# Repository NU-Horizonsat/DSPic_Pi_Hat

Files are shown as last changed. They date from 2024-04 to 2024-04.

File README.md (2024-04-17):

# DSPic_Pi_Hat
A Raspberry Pi hat with a DSPic and USB.

To-do list:

## schematic

- [x] USB
- [x] UART chip
- [x] Verify chip selected 
- [ ] Wire DSPic 
    - [x] Wire dubug port
    - [ ] 1n4148 to MCLR?
    - [x] Add oscillator
    - [ ] Check oscillator
    - [x] Wire ADC pins
    - [ ] Check ADC connections
    - [x] Wire PWM pins
    - [x] ~~Wire i2c~~
        - [x] might not even need that (dont need it)
    - [x] rework connectors
    - [x] Dip switches
    - [x] Status LEDs
- [x] Wire to Pi GPIO
    - [x] Power pins
    - [x] Pi to DSPic
    - [x] Screen connectors
    - [x] Status LEDs
- [x] Add ICSP header
    - [ ] Second header for slave core?
- [x] Add connectors for coil drivers
- [ ] Add chip protection
    - [x] Add linear regulator
    - [x] ~~I2C protection~~
    - [x] PWM protection
    - [x] ADC protection
    - [x] Check to make sure the ESD would work
- [x] Find polyfuse to use
- [x] Find capacitor value for C5
- [x] Find crystal
- [x] Find inductor 
- [x] Finalize resistor and led paring 
- [x] Add connector for other PSU

## PCB
- [ ] Test points
- [ ] Add pcb art
- [x] Assign all footprints
- [x] Proper edge cuts for hat
- [x] Grounded screw holes
- [ ] Check footprints
- [x] Connectors and ESD
- [x] USB c and power
- [x] UART
- [x] DSPic

## Parts to order for hand soldering

| Part  | Number | Link |
| --- | --- | --- |
| Crystal  | 1  | https://www.digikey.com/en/products/detail/kyocera-avx/KC2520Z100-000C15XXK/11610165 |
| Inductor  | 1 | https://www.digikey.com/en/products/detail/delta-electronics-components/0805CS-621EGTS/9763907 |
| Amp Connector | 3 | https://www.digikey.com/en/products/detail/molex/5015680807/1531491 | 
| External Power | 1 | https://www.digikey.com/en/products/detail/molex/5015680207/1531485 | 
| Qwiic | 1 | https://www.digikey.com/short/mfth8vvv |
| Raspi Header | 1 | https://www.digikey.com/en/products/detail/sullins-connector-solutions/SFH11-PBPC-D20-ST-BK/1990093 |
| Programming header | 1 | https://www.digikey.com/en/products/detail/samtec-inc/TD-103-T-A/1105555 | 
| Jumper | 1 | https://www.digikey.com/en/products/detail/mill-max-manufacturing-corp/342-10-102-00-591000/4455936 |
| Fuse | 1 | https://www.digikey.com/en/products/detail/littelfuse-inc/1210L500-12SLWR/12807041 |
| Dip switches | 1 | https://www.digikey.com/en/products/detail/cts-electrocomponents/208-8/20795 |

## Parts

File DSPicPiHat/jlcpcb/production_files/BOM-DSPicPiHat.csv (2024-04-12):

Comment | Designator | Footprint | LCSC
FerriteBead_Small | FB1 | R_1206_3216Metric | C1017
NCP1117-3.3_SOT223 | U12 | SOT-223-3_TabPin2 | C146799
47pf | C16,C17 | C_0805_2012Metric | C14857
10uf | C19,C22 | C_0805_2012Metric | C15850
10nf | C18 | C_0805_2012Metric | C1710
10k | R17,R18,R19,R20,R21,R22,R23,R24,R3 | R_0805_2012Metric | C17414
10 o | R10,R11,R12,R7,R8,R9 | R_0805_2012Metric | C17415
470o | R4,R6 | R_0805_2012Metric | C17710
12pF | C13,C14 | C_0603_1608Metric | C1792
4.7uf | C21 | CP_Elec_4x5.4 | C213488
POWER_Select | SW1 | SW_SPDT_PCM12 | C221841
DF5A6.2CJE_LM | U10,U3,U4,U6,U7,U9 | SOT-553 | C2762689
5.1k | R13,R14 | R_0805_2012Metric | C27834
0.1uf Cer | C10,C11,C12,C15,C20,C5,C6,C9 | C_0805_2012Metric | C28233
USB_C_Receptacle_USB2.0 | J5 | USB_C_Receptacle_HRO_TYPE-C-31-M-12 | C2927038
Led | D1,D10,D11,D2,D3,D6,D7,D8,D9 | LED_0805_2012Metric | C34499
27o | R15,R16 | R_0805_2012Metric | C365278
WS2812B | D12,D13,D4,D5 | LED_WS2812B-2020_PLCC4_2.0x2.0mm | C4154877
FT230XS | U11 | SSOP-16_3.9x4.9mm_P0.635mm | C69082
Conn_01x04_Female | J2 | JST_SH_BM04B-SRSS-TB_1x04-1MP_P1.00mm_Vertical
Fiducial | FID1 | Fiducial_1mm_Mask2mm
0 ohm | R2 | R_0805_2012Metric
0 ohm | R5 | R_0805_2012Metric
0 ohm | R1 | R_0805_2012Metric
Jumper_2_Open | JP1 | PinHeader_1x02_P2.54mm_Vertical
Conn_PIC_ICSP_ICD | J4 | PinHeader_2x03_P2.54mm_Vertical
SW_DIP_x08 | SW2 | SW_DIP_SPSTx08_Slide_9.78x22.5mm_W7.62mm_P2.54mm
MountingHole_Pad | H4 | MountingHole_2.7mm_M2.5_DIN965_Pad
TestPoint | TP1 | TestPoint_Pad_D1.0mm
0 ohm | R25 | R_0805_2012Metric
0 ohm | R26 | R_0805_2012Metric
TestPoint | TP2 | TestPoint_Pad_D1.0mm
100MHz | Y1 | Crystal_SMD_2520-4Pin_2.5x2.0mm
Fiducial | FID3 | Fiducial_1mm_Mask2mm
MountingHole_Pad | H1 | MountingHole_2.7mm_M2.5_DIN965_Pad
DSPIC33CH512MP508T-I_PT | U1 | TQFP-80_12x12mm_P0.5mm
Conn_01x08 | Connector_X1 | Molex_Pico-Clasp_202396-0807_1x08-1MP_P1.00mm_Horizontal
6.33 mH | L1 | L_0805_2012Metric
Fiducial | FID2 | Fiducial_1mm_Mask2mm
Conn_01x08 | Connector_Y1 | Molex_Pico-Clasp_202396-0807_1x08-1MP_P1.00mm_Horizontal
Conn_01x08 | Connector_Z1 | Molex_Pico-Clasp_202396-0807_1x08-1MP_P1.00mm_Horizontal
MountingHole_Pad | H2 | MountingHole_2.7mm_M2.5_DIN965_Pad
PowerInput | J6 | Molex_Pico-Clasp_202396-0207_1x02-1MP_P1.00mm_Horizontal
5 a | F1 | Fuse_1210_3225Metric
Conn_01x09_Female | J1 | PinHeader_1x09_P2.54mm_Vertical
MountingHole_Pad | H3 | MountingHole_2.7mm_M2.5_DIN965_Pad
RasPiHeaders | J8 | PinSocket_2x20_P2.54mm_Vertical

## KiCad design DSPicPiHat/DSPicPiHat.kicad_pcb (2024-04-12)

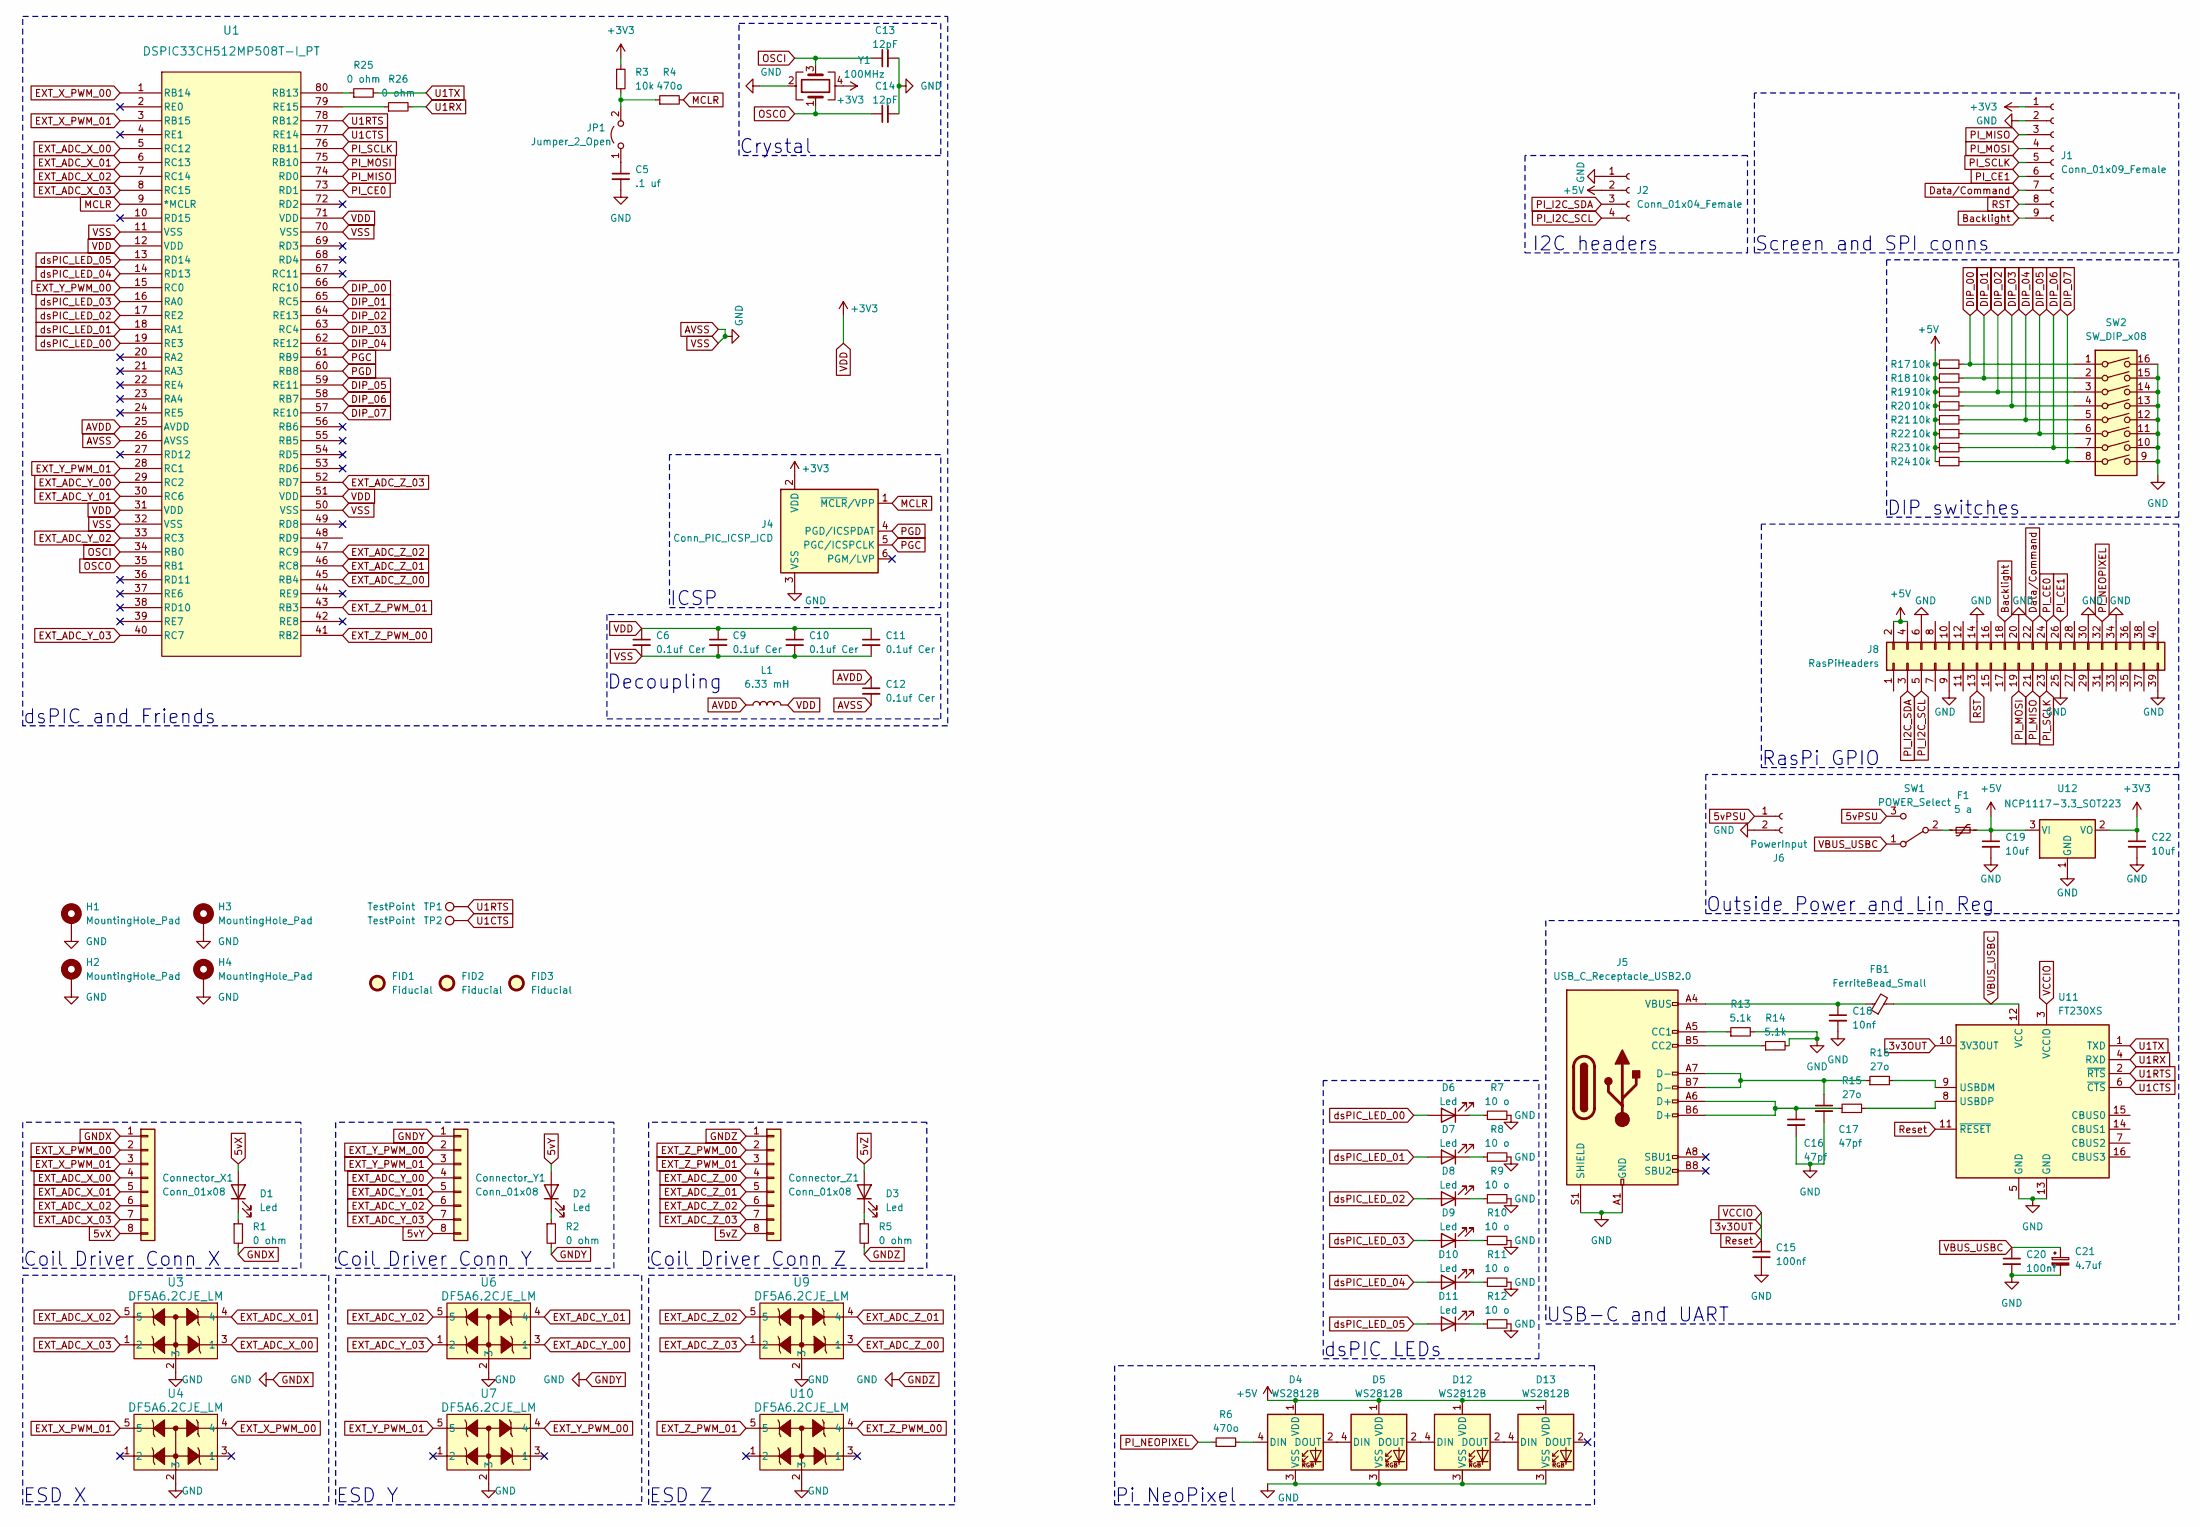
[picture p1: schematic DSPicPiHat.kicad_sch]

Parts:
C5: .1 uf; C_0805_2012Metric
C6, C9, C10, C11, C12: 0.1uf Cer; C_0805_2012Metric
C13, C14: 12pF; C_0603_1608Metric
C15, C20: 100nf; C_0805_2012Metric
C16, C17: 47pf; C_0805_2012Metric
C18: 10nf; C_0805_2012Metric
C19, C22: 10uf; C_0805_2012Metric
C21: 4.7uf; CP_Elec_4x5.4
Connector_X1: Conn_01x08; Molex_Pico-Clasp_202396-0807_1x08-1MP_P1.00mm_Horizontal
Connector_Y1: Conn_01x08; Molex_Pico-Clasp_202396-0807_1x08-1MP_P1.00mm_Horizontal
Connector_Z1: Conn_01x08; Molex_Pico-Clasp_202396-0807_1x08-1MP_P1.00mm_Horizontal
D1, D2, D3, D6, D7, D8, D9, D10, D11: Led; LED_0805_2012Metric
D4, D5, D12, D13: WS2812B; LED_WS2812B-2020_PLCC4_2.0x2.0mm
F1: 5 a; Fuse_1210_3225Metric
FB1: FerriteBead_Small; R_1206_3216Metric
FID1, FID2, FID3: Fiducial; Fiducial_1mm_Mask2mm
H1, H2, H3, H4: MountingHole_Pad; MountingHole_2.7mm_M2.5_DIN965_Pad
J1: Conn_01x09_Female; PinHeader_1x09_P2.54mm_Vertical
J2: Conn_01x04_Female; JST_SH_BM04B-SRSS-TB_1x04-1MP_P1.00mm_Vertical
J4: Conn_PIC_ICSP_ICD; PinHeader_2x03_P2.54mm_Vertical
J5: USB_C_Receptacle_USB2.0; USB_C_Receptacle_HRO_TYPE-C-31-M-12
J6: PowerInput; Molex_Pico-Clasp_202396-0207_1x02-1MP_P1.00mm_Horizontal
J8: RasPiHeaders; PinSocket_2x20_P2.54mm_Vertical
JP1: Jumper_2_Open; PinHeader_1x02_P2.54mm_Vertical
L1: 6.33 mH; L_0805_2012Metric
R1, R2, R5, R25, R26: 0 ohm; R_0805_2012Metric
R3, R17, R18, R19, R20, R21, R22, R23, R24: 10k; R_0805_2012Metric
R4, R6: 470o; R_0805_2012Metric
R7, R8, R9, R10, R11, R12: 10 o; R_0805_2012Metric
R13, R14: 5.1k; R_0805_2012Metric
R15, R16: 27o; R_0805_2012Metric
SW1: POWER_Select; SW_SPDT_PCM12
SW2: SW_DIP_x08; SW_DIP_SPSTx08_Slide_9.78x22.5mm_W7.62mm_P2.54mm
TP1, TP2: TestPoint; TestPoint_Pad_D1.0mm
U1: DSPIC33CH512MP508T-I_PT; TQFP-80_12x12mm_P0.5mm
U3, U4, U6, U7, U9, U10: DF5A6.2CJE_LM; SOT-553
U11: FT230XS; SSOP-16_3.9x4.9mm_P0.635mm
U12: NCP1117-3.3_SOT223; SOT-223-3_TabPin2
Y1: 100MHz; Crystal_SMD_2520-4Pin_2.5x2.0mm

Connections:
3v3OUT: C15.1, U11.3 (VCCIO), U11.10 (3V3OUT), U11.11 (~RESET)
5vPSU: J6.1, SW1.3 (C)
5vX: Connector_X1.8, D1.2 (A)
5vY: Connector_Y1.8, D2.2 (A)
5vZ: Connector_Z1.8, D3.2 (A)
+5V: C19.1, D4.1 (VDD), D5.1 (VDD), D12.1 (VDD), D13.1 (VDD), F1.2, J2.2, J8.2, J8.4, R17.1, R18.1, R19.1, R20.1, R21.1, R22.1, R23.1, R24.1, U12.3 (VI)
AVDD: C12.1, L1.1, U1.25 (AVDD)
AVSS: C5.2, C6.2, C9.2, C10.2, C11.2, C12.2, C13.2, C14.2, C15.2, C16.2, C17.2, C18.2, C19.2, C20.2, C21.2, C22.2, Connector_X1.1, Connector_Y1.1, Connector_Z1.1, D4.3 (VSS), D5.3 (VSS), D12.3 (VSS), D13.3 (VSS), H1.1, H2.1, H3.1, H4.1, J1.2, J2.1, J4.3 (VSS), J5.A1 (GND), J5.A12 (GND), J5.B1 (GND), J5.B12 (GND), J5.S1 (SHIELD), J6.2, J8.6, J8.9, J8.14, J8.20, J8.25, J8.30, J8.34, J8.39, R1.2, R2.2, R5.2, R7.2, R8.2, R9.2, R10.2, R11.2, R12.2, R13.2, R14.2, SW2.9, SW2.10, SW2.11, SW2.12, SW2.13, SW2.14, SW2.15, SW2.16, U1.11 (VSS), U1.26 (AVSS), U1.32 (VSS), U1.50 (VSS), U1.70 (VSS), U3.2 (3), U4.2 (3), U6.2 (3), U7.2 (3), U9.2 (3), U10.2 (3), U11.5 (GND), U11.13 (GND), U12.1 (GND), Y1.2
Backlight: J1.9, J8.18
DIP_00: R17.2, SW2.1, U1.66 (RC10)
DIP_01: R18.2, SW2.2, U1.65 (RC5)
DIP_02: R19.2, SW2.3, U1.64 (RE13)
DIP_03: R20.2, SW2.4, U1.63 (RC4)
DIP_04: R21.2, SW2.5, U1.62 (RE12)
DIP_05: R22.2, SW2.6, U1.59 (RE11)
DIP_06: R23.2, SW2.7, U1.58 (RB7)
DIP_07: R24.2, SW2.8, U1.57 (RE10)
Data/Command: J1.7, J8.22
EXT_ADC_X_00: Connector_X1.4, U1.5 (RC12), U3.3 (1)
EXT_ADC_X_01: Connector_X1.5, U1.6 (RC13), U3.4
EXT_ADC_X_02: Connector_X1.6, U1.7 (RC14), U3.5
EXT_ADC_X_03: Connector_X1.7, U1.8 (RC15), U3.1 (2)
EXT_ADC_Y_00: Connector_Y1.4, U1.29 (RC2), U6.3 (1)
EXT_ADC_Y_01: Connector_Y1.5, U1.30 (RC6), U6.4
EXT_ADC_Y_02: Connector_Y1.6, U1.33 (RC3), U6.5
EXT_ADC_Y_03: Connector_Y1.7, U1.40 (RC7), U6.1 (2)
EXT_ADC_Z_00: Connector_Z1.4, U1.45 (RB4), U9.3 (1)
EXT_ADC_Z_01: Connector_Z1.5, U1.46 (RC8), U9.4
EXT_ADC_Z_02: Connector_Z1.6, U1.47 (RC9), U9.5
EXT_ADC_Z_03: Connector_Z1.7, U1.52 (RD7), U9.1 (2)
EXT_X_PWM_00: Connector_X1.2, U1.1 (RB14), U4.4
EXT_X_PWM_01: Connector_X1.3, U1.3 (RB15), U4.5
EXT_Y_PWM_00: Connector_Y1.2, U1.15 (RC0), U7.4
EXT_Y_PWM_01: Connector_Y1.3, U1.28 (RC1), U7.5
EXT_Z_PWM_00: Connector_Z1.2, U1.41 (RB2), U10.4
EXT_Z_PWM_01: Connector_Z1.3, U1.43 (RB3), U10.5
MCLR: J4.1 (~MCLR/VPP), R4.2, U1.9 (*MCLR)
unnamed: C16.1, J5.A6 (D+), J5.B6 (D+), R15.1
unnamed: C17.1, J5.A7 (D-), J5.B7 (D-), R16.1
unnamed: C18.1, FB1.1, J5.A4 (VBUS), J5.A9 (VBUS), J5.B4 (VBUS), J5.B9 (VBUS)
unnamed: D1.1 (K), R1.1
unnamed: D2.1 (K), R2.1
unnamed: D3.1 (K), R5.1
unnamed: D4.4 (DIN), R6.2
unnamed: D4.2 (DOUT), D5.4 (DIN)
unnamed: D6.1 (K), R7.1
unnamed: D7.1 (K), R8.1
unnamed: D8.1 (K), R9.1
unnamed: D9.1 (K), R10.1
unnamed: D10.1 (K), R11.1
unnamed: D11.1 (K), R12.1
unnamed: D5.2 (DOUT), D12.4 (DIN)
unnamed: D12.2 (DOUT), D13.4 (DIN)
unnamed: J5.A5 (CC1), R13.1
unnamed: J5.B5 (CC2), R14.1
unnamed: C5.1, JP1.1 (A)
unnamed: JP1.2 (B), R3.2, R4.1
unnamed: F1.1, SW1.2 (B)
unnamed: R25.1, U1.80 (RB13)
unnamed: R26.1, U1.79 (RE15)
unnamed: R16.2, U11.9 (USBDM)
unnamed: R15.2, U11.8 (USBDP)
OSCI: C13.1, U1.34 (RB0), Y1.3
OSCO: C14.1, U1.35 (RB1), Y1.1
PGC: J4.5 (PGC/ICSPCLK), U1.61 (RB9)
PGD: J4.4 (PGD/ICSPDAT), U1.60 (RB8)
PI_CE0: J8.24, U1.73 (RD1)
PI_CE1: J1.6, J8.26
PI_I2C_SCL: J2.4, J8.5
PI_I2C_SDA: J2.3, J8.3
PI_MISO: J1.3, J8.21, U1.74 (RD0)
PI_MOSI: J1.4, J8.19, U1.75 (RB10)
PI_NEOPIXEL: J8.32, R6.1
PI_SCLK: J1.5, J8.23, U1.76 (RB11)
RST: J1.8, J8.13
U1CTS: TP2.1, U1.77 (RE14), U11.6 (~CTS)
U1RTS: TP1.1, U1.78 (RB12), U11.2 (~RTS)
U1RX: R26.2, U11.4 (RXD)
U1TX: R25.2, U11.1 (TXD)
VBUS_USBC: C20.1, C21.1, FB1.2, SW1.1 (A), U11.12 (VCC)
VDD: C6.1, C9.1, C10.1, C11.1, C22.1, J1.1, J4.2 (VDD), L1.2, R3.1, U1.12 (VDD), U1.31 (VDD), U1.51 (VDD), U1.71 (VDD), U12.2 (VO), Y1.4
dsPIC_LED_00: D6.2 (A), U1.19 (RE3)
dsPIC_LED_01: D7.2 (A), U1.18 (RA1)
dsPIC_LED_02: D8.2 (A), U1.17 (RE2)
dsPIC_LED_03: D9.2 (A), U1.16 (RA0)
dsPIC_LED_04: D10.2 (A), U1.14 (RD13)
dsPIC_LED_05: D11.2 (A), U1.13 (RD14)

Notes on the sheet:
Decoupling
USB-C and UART
Pi NeoPixel
ICSP
dsPIC LEDs
RasPi GPIO
Screen and SPI conns
Outside Power and Lin Reg
I2C headers
ESD Z
ESD Y
dsPIC and Friends
Coil Driver Conn Y
DIP switches
Crystal
Coil Driver Conn Z
Coil Driver Conn X
ESD X

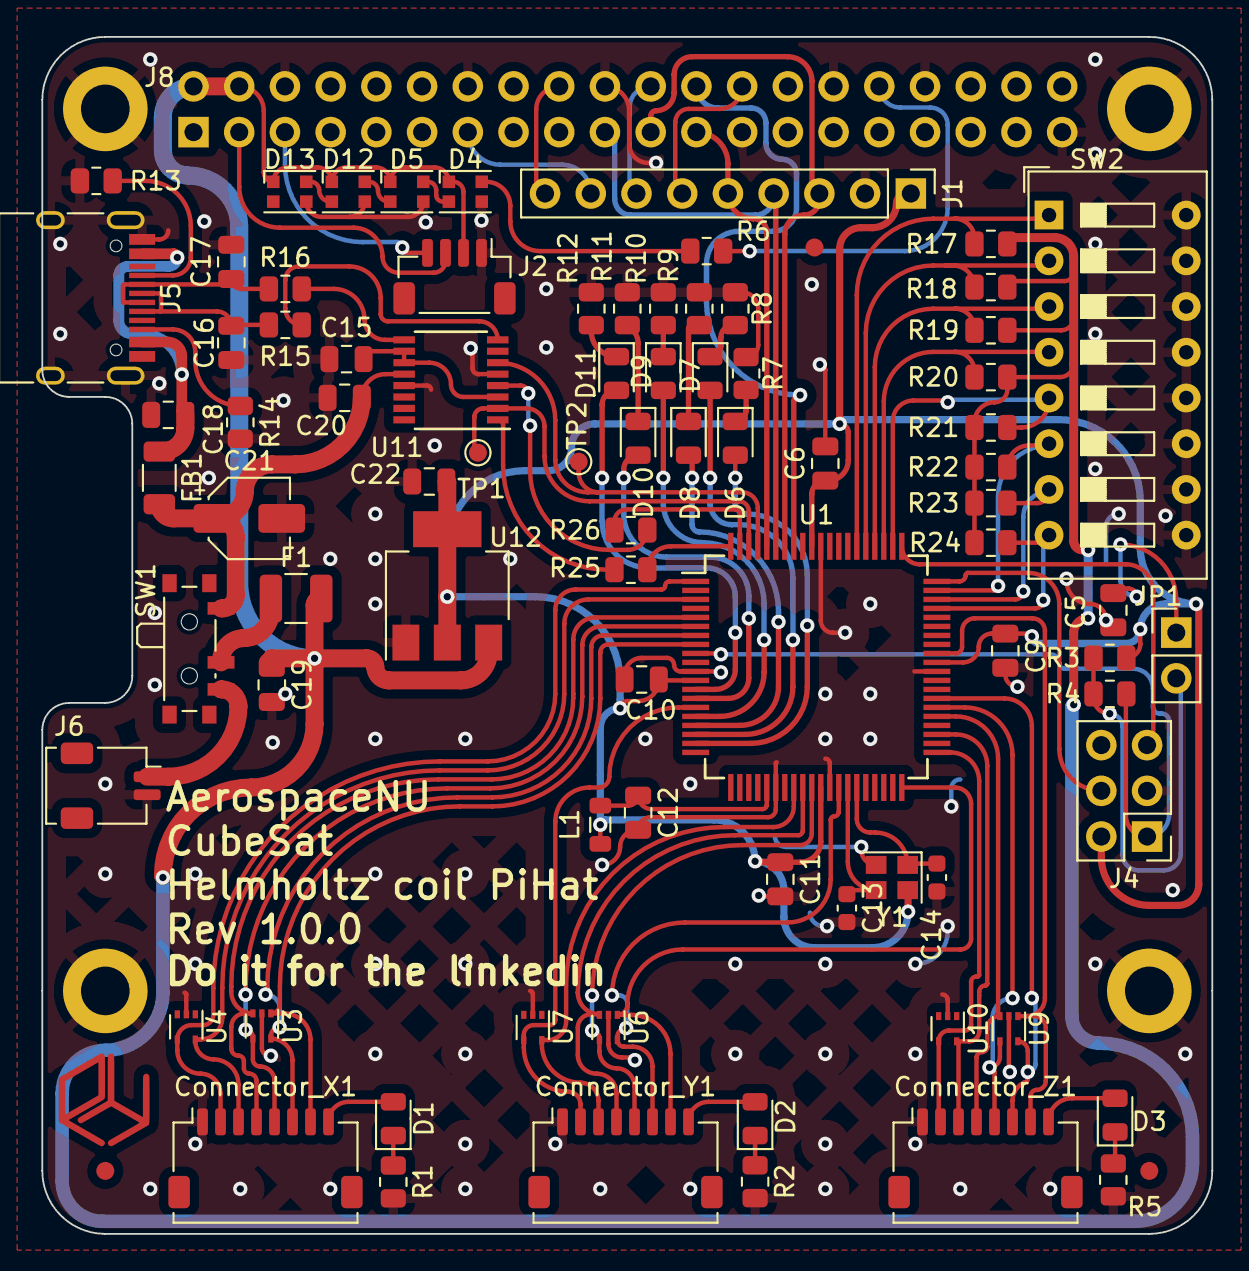
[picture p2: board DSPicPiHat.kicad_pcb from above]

Board: 2 copper layers, 65.0 x 66.5 mm, 89 parts (1 on the bottom side), 87 nets.

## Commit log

2024-03-01 Started work on schematic
    added the correct DSPic (i think), added usb, headers, and power spdt. Added gitignore file for the backups folder.
    [DSPicPiHat.kicad_pcb, DSPicPiHat.kicad_sch]
2024-03-01 Added USB wiring and UART chip
    [DSPicPiHat.kicad_sch]
2024-03-02 Added linear regulator expanded to-do list
2024-03-02 Added debug port, polyfuse, and organizational changes.
    [DSPicPiHat.kicad_sch]
2024-03-02 Added correct dsPIC chip and connected it to parts., added coil driver connector, added tvs diodes.
    [DSPicPiHat.kicad_sch]
2024-03-02 Wire ADC to dsPIC, moved things around.
    [DSPicPiHat.kicad_sch]
2024-03-02 each axis needs own conn
    [DSPicPiHat.kicad_sch]
2024-03-03 more coil driver headers and protection
    [DSPicPiHat.kicad_sch]
2024-03-03 added leds to coil connector plugs
    [DSPicPiHat.kicad_sch]
2024-03-03 wired up i2c, PWM, and ADC pins from connectors
    [DSPicPiHat.kicad_sch]
2024-03-04 dsPIC to Pi, dsPIC dip switches, dspic and Pi LEDs, and spi screen connectors.
    [DSPicPiHat.kicad_sch]
2024-03-22 fix connector connections and remove extra ones, switches resistor array for multiple resistors
    [DSPicPiHat.kicad_sch]
2024-03-22 start adding pcb footprints, working on pcb outline, and starting routing.
    Also removed resistor array.
    [DSPicPiHat.kicad_pcb, DSPicPiHat.kicad_sch]
2024-03-22 ESD connected to axis connectors.
    [DSPicPiHat.kicad_pcb, DSPicPiHat.kicad_sch]
2024-03-23 Power, USB, and UART
    [DSPicPiHat.kicad_sch]
2024-03-23 Connected all the coil driver connectors. Added more footprints.
    [DSPicPiHat.kicad_pcb, DSPicPiHat.kicad_sch]
2024-03-24 PCB mostly routed
    [DSPicPiHat.kicad_pcb, DSPicPiHat.kicad_sch]
2024-03-27 changed connectors and removed i2c lines and i2c isolator.
    [DSPicPiHat.kicad_pcb, DSPicPiHat.kicad_sch]
2024-03-27 added fiducials and slightly moved some things around.
    [DSPicPiHat.kicad_pcb]
2024-03-29 Adjusting silk screen locations
    [DSPicPiHat.kicad_pcb, DSPicPiHat.kicad_sch]
2024-03-29 Rounded some comers and added more pcb art
    [DSPicPiHat.kicad_pcb]
2024-03-29 Grounded mounting points
    [DSPicPiHat.kicad_pcb, DSPicPiHat.kicad_sch]
2024-04-02 Fixed pi header connections
    [DSPicPiHat.kicad_pcb, DSPicPiHat.kicad_sch]
2024-04-03 Moved fuse to be after the PSU switch
    [DSPicPiHat.kicad_pcb, DSPicPiHat.kicad_sch]
2024-04-06 added o ohm resistors based on braincodec's rx tx switcher
    [DSPicPiHat.kicad_pcb, DSPicPiHat.kicad_sch]
2024-04-08 dip_00 was unconnected, working through drc errors and warnings.
    [DSPicPiHat.kicad_pcb, DSPicPiHat.kicad_sch]
2024-04-09 made a few traces slightly thicker
    [DSPicPiHat.kicad_pcb]
2024-04-09 organized schem
    [DSPicPiHat.kicad_sch]
2024-04-10 filling in unkown values and footprints
    [DSPicPiHat.kicad_pcb, DSPicPiHat.kicad_sch]
2024-04-10 removed islands, added more vias, fixed routing, added no connect.
    [DSPicPiHat.kicad_pcb, DSPicPiHat.kicad_sch]
2024-04-10 Added more vias, removed some hanging ground pours, updated drc and fixed any errors.
    [DSPicPiHat.kicad_pcb]
2024-04-11 made small fixes and finishing touches
    [DSPicPiHat.kicad_pcb, DSPicPiHat.kicad_sch]
2024-04-11 kicad v8!
    [DSPicPiHat.kicad_pcb, DSPicPiHat.kicad_sch]
2024-04-11 started work on selecting parts for pcba
    [DSPicPiHat.kicad_pcb, DSPicPiHat.kicad_sch]
2024-04-12 more basic parts!
    [BOM-DSPicPiHat.csv, DSPicPiHat.kicad_pcb, DSPicPiHat.kicad_sch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]
2024-04-12 added more parts to bom
    [DSPicPiHat.kicad_pcb, DSPicPiHat.kicad_sch]
2024-04-12 generate production files
    [BOM-DSPicPiHat.csv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]
